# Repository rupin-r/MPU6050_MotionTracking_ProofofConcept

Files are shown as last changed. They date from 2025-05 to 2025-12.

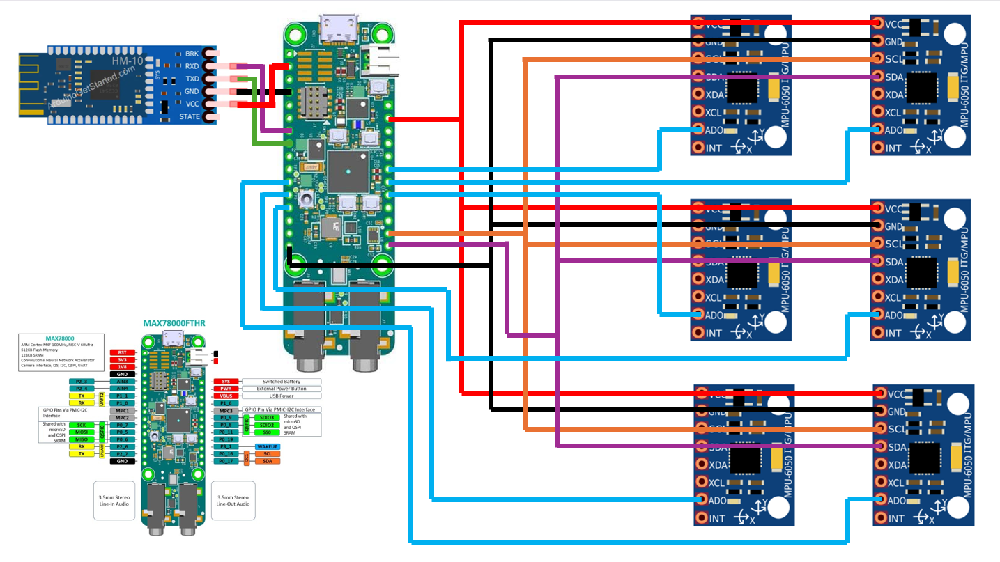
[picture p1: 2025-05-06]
WiringDiagram.png

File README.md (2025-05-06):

# MPU6050_MotionTracking_ProofofConcept
-------------------
About
-------------------

Contributors: Rupin Raj Kumar Pradeep

Project Description: WPI ECE556 Deep Learning On Embedded Devices class project.

Characterize motions into 5 general categories (similar to existing work) of walking, standing, sitting, going upstairs, and going downstairs using 6 MPU6050s placed on the body.

--------------------
Features
--------------------

Includes an Eclipse IDE project generated by the MAXIM_SDK and further edited for input handling and processing. Also includes data for training and testing assuming orientation and position generally matches.

The main code solution is meant to run on a MAX78000FTHR board connected to 6 MPU6050s and a HM-10 or HM-20 BlueTooth module as seen in the wiring diagram presented further down.

--------------------
Required Materials
--------------------

-1 MAX78000FTHR

-6 MPU6050

-1 Breadboard or custom PCB

-30 very long (preferably custom cut) male-to-female wires (for IMU connection to PCB)

-10 short male-to-female wires (for MAX78000FTHR connection to PCB)

-4 short female-to-female wires (typically comes with HM-20 to connect to MAX78000 FTHR

-1 micro-USB to USB A cable with data transfer

-1 Arduino UNO for preliminary data gathering or testing if required

-2 rolls of Velcro strap

-A power source (Arduino kit 9V battery with power supply module is suitable)

-An iPhone with the app BluetoothLE Bluetooth Terminal by Lukas Pistrol
Is it trustworthy? I don't know, but other bluetooth terminals place a character limit at 8 or 16 character transfers

--------------------
Resources and References
--------------------

-Device setup resources and auto-generated deep learning code

https://github.com/analogdevicesinc/MaximAI_Documentation/tree/main/MAX78000_Feather

https://github.com/analogdevicesinc/ai8x-synthesis/blob/develop/README.md

https://analogdevicesinc.github.io/msdk/USERGUIDE/

-Input handling code resources

https://github.com/ElectronicCats/mpu6050/blob/master/src/MPU6050.cpp

https://invensense.tdk.com/wp-content/uploads/2015/02/MPU-6000-Register-Map1.pdf

https://jake-carter.github.io/msdk/Libraries/PeriphDrivers/Documentation/MAX78002/group__i2c.html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

https://jake-carter.github.io/msdk/Libraries/PeriphDrivers/Documentation/MAX32520/group__gpio.html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

https://jake-carter.github.io/msdk/Libraries/PeriphDrivers/Documentation/MAX32650/group__uart.html

https://www.analog.com/media/en/technical-documentation/user-guides/max78000-user-guide.pdf

--------------------
Design
--------------------

***Wiring Diagram***

See file WiringDiagram.png

***MPU Positioning***

See file BodyPlacement.png

***Neural Network Architecture***

See imu.yaml in the Neural Network folder

SUMMARY OF OPS

Hardware: 1,715,382 ops (1,703,817 macc; 11,565 comp; 0 add; 0 mul; 0 bitwise)

    Layer 0 (trans_conv1_ConvTranspose_8): 622,080 ops (622,080 macc; 0 comp; 0 add; 0 mul; 0 bitwise)
    
    Layer 1 (trans_conv2_ConvTranspose_6): 663,552 ops (663,552 macc; 0 comp; 0 add; 0 mul; 0 bitwise)
    
    Layer 2 (conv1_Conv_6): 336,384 ops (331,776 macc; 4,608 comp; 0 add; 0 mul; 0 bitwise)
    
    Layer 3 (conv2_Conv_6): 88,704 ops (82,944 macc; 5,760 comp; 0 add; 0 mul; 0 bitwise)
    
    Layer 4 (conv3_Conv_6): 4,437 ops (3,240 macc; 1,197 comp; 0 add; 0 mul; 0 bitwise)
    
    Layer 5 (fc_Gemm_4): 225 ops (225 macc; 0 comp; 0 add; 0 mul; 0 bitwise)

RESOURCE USAGE
    
    Weight memory: 7,209 bytes out of 442,368 bytes total (1.6%)
    
    Bias memory:   50 bytes out of 2,048 bytes total (2.4%)

AIM

The neural network should be small and extremely, but this was a lot smaller than it could have been considering it takes up < 3% of the processor space.

Since the input is considered small ([30, 6, 6]), the goal was to enlarge the sample first, then go further down to the 5 output classification.

Therefore, the first two layers undergo 2D Convolutional Transpose, but were unable to quickly increase the size due to hardware constraints on kernel size.

The next convolutional layers bring the size back down.

Further work can be done in changing the model to a larger model with more convolutional transposes for better results.

However, irregardless of size, the network was able to have high accuracy with 8-bit quantization (it might also be a little overfit, but that was intentional).

    2025-05-05 01:05:35,825 - ==> Top1: 97.833    Loss: 0.083

    2025-05-05 01:05:35,826 - ==> Confusion:
    
    [[ 373    5    0    0   12]
    
     [   1 3259    1    0   93]
    
     [   0    4 2935    0    1]
     
     [   0    0    1  366    0]
     
     [   1   86    0    0 2324]]

 This was not able to be tested with further real world data because of failed I2C communications and wires breaking. However, it did classify all 0s as sitting which is pretty good.

 CONSIDERATIONS

 The neural network runs in series with data collection. Due to the current I2C characteristics seen on both the Arduino and MAX78000FTHR, each sample takes ~10 ms for a single [1,6,6] capture.
 Therefore, 3 seconds after device and data initialization are needed before the first classification. After the 3 seconds, frames are sampled every second by pushing in 8 frames and popping 8 frames.
 For consistency in collected data from input data to training data, inference time should approach 0. However, if implemented on a separate thread, the inference time would only have to be less than 1 second. 
 In such a case, frame time can be extended for bigger frames and the model can be even bigger.

--------------------
Reproduction
--------------------
 
This guide is specifically for Windows 10/11 using Eclipse SDK

***SETUP DRIVER***

Follow the steps in https://github.com/analogdevicesinc/MaximAI_Documentation/tree/main/MAX78000_Feather for getting started. If the link does not redirect, in the directory on the left hand side, select MAX78000_Evaluation_Kit. Then double click in MAX32625PICO_files. The device driver is there for the adapter firmware.

***SOFTWARE DOWNLOAD***

Go to this link: https://www.analog.com/en/resources/evaluation-hardware-and-software/embedded-development-software/software-download.html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. Then click MaximMicrosSDK_win.exe and download it. You may need to create an account for this. Run the executable and install everything into the default directory. After installing everything, eclipse SDK should be accessible. Before opening eclipse SDK, copy the folder imu_fixed_inputs_no_softmax into C:/MaximSDK/Examples/MAX78000

Run MinGw to setup your environment. Change directory in the terminal of MinGw to the imu_fixed_inputs_no_softmax folder. Run 'make' and ensure the file builds. Once the file is built, you can upload the code to the board using 'make flash.openocd'. If the file doesn't build, you may need to install some additional stuff. This would include cloning the msdk git repository and creating a symbolic link to MaximSDK Tools. Details on these instructions can be found here: https://github.com/analogdevicesinc/msdk/blob/main/README.md

***RUNNING THE PROGRAM***

The program automatically starts after flashing. The program then restarts everytime it is powered on. You can debug the program using MinGw by typing 'openocd -s $MAXIM_PATH/Tools/OpenOCD/scripts -f interface/cmsis-dap.cfg -f target/max78000.cfg -c "program build/max78000.elf verify; init; reset halt"' into one MinGw terminal and 'arm-none-eabi-gdb --se=build/max78000.elf' into another MinGw terminal. The second command starts a gdb debugger. Before you start debugging, type in 'target extended-remote localhost:3333' and press enter. Then run 'monitor reset halt' and you can debug the program. More information can be found here: https://analogdevicesinc.github.io/msdk/USERGUIDE/#command-line-development

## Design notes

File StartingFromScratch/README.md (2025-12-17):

# Programming a Model from Scratch
-------------------
Instructions
-------------------

Most instructions for setting up and running a model can be found by altering instructions for mnist in the tutorial found here: https://github.com/analogdevicesinc/ai8x-synthesis/blob/develop/README.md and here: https://github.com/analogdevicesinc/ai8x-training?tab=readme-ov-file

The instructions found here are a simplification specific to the data presented here and Windows 10/11 with Windows Subsystem for Linux.

***Install Ubuntu 22.04.5***

Open a command prompt as administrator and run:

    C:\> wsl --install

Then restart your computer (not just your terminal)

Open the Microsoft store and install Ubuntu 22.04.5

You can now open a WSL terminal by searching Ubuntu in the start bar

Open a WSL terminal and run:

    sudo apt upgrade

    sudo apt update

Then run the following command to install dependencies:

    sudo apt-get install -y make build-essential libssl-dev zlib1g-dev libbz2-dev libreadline-dev libsqlite3-dev wget curl llvm libncurses5-dev libncursesw5-dev xz-utils tk-dev libffi-dev liblzma-dev libsndfile-dev portaudio19-dev libsox-dev

After installing dependencies, install python3 with:

    curl -L https://github.com/pyenv/pyenv-installer/raw/master/bin/pyenv-installer | bash

The terminal will then prompt you to add lines to one or more of ~/.bash_profile, ~/.bashrc, ~/.zshrc, ~/.profile, or ~/.zprofile

You can open one of these files using nano to edit them. For instance:

    nano ~/.profile

Copy the lines given to you at the end of the files prompted by the terminal. Using nano, use CTRL + X to exit and save to a file.

Close the terminal and open a new WSL terminal

***Install ai8x-trainer and ai8x-synthesizer***

Install python using:

    pyenv install 3.11.8

Establish git profile using:

    git config --global user.email "email@example.com"

    git config --global user.name "username"

Create a directory to store your files in with mkdir:

    mkdir example

    cd example

Then clone the repositories into this directory:

    git clone --recursive https://github.com/analogdevicesinc/ai8x-training.git

    git clone --recursive https://github.com/analogdevicesinc/ai8x-synthesis.gi

Run the following lines to set up a virtual environment to use in the training folder:

    cd ai8x-training

    pyenv local 3.11.8

    python -m venv .venv --prompt ai8x-training

    echo "*" > .venv/.gitignore

    source .venv/bin/activate

You can exit the virtual environment using:

    deactivate

You can restart the virtual environment for any work you need to do in training just with:

    source .venv/bin/activate

Before deactivating the training virtual environment (or restart it if you have), install more dependencies:

    pip3 install -U pip wheel setuptools

    pip3 install -r requirements.txt --extra-index-url https://download.pytorch.org/whl/cu121

Run the following lines to set up a virtual environment to use in the synthesis folder:

    cd ../ai8x-synthesis

    pyenv local 3.11.8

    python -m venv .venv --prompt ai8x-synthesis

    echo "*" > .venv/.gitignore

    source .venv/bin/activate

You can exit the virtual environment using:

    deactivate

You can restart the virtual environment for any work you need to do in training just with:

    source .venv/bin/activate

Again, before deactivating, install more dependencies:

    pip3 install -U pip setuptools

    pip3 install -r requirements.txt

***Data Loader***

To start training the model, the data must be loaded into a created/selected model

Specifically, data must be accessible through the dataset class as it allows for indexed access of data

You can follow the template given by training/imu.py which loads data from a json file

The class IMU_AI holds the dataset and allows for indexing of elements of the dataset. It also contains a loader which gives access to both the train and test datasets.

These must then be defined in a dataset construct at the end as shown in the file

Then you need to select/create a model. The github for training and synthesis comes with premade models, but you can choose to make your own following the same format. I chose to use a premade model: ai85net.py

Lastly, you put all these parameters together into the training file to actually train the model. There are two main files to look at: train_kinetics.sh and evaluate_kinetics.sh. These files were edited from their original implementation as an example to use with the IMU dataset of this project.

You can edit any parameters for training or evaluating the model and more details can be found on their website: https://github.com/analogdevicesinc/ai8x-training?tab=readme-ov-file

***Synthesizing***

Synthesizing turns the created model into an embedded C program for the TPU on the MAX78000 to run

First you need a model formatted to yaml as seen in synthesis/imu.yaml

This was taken from the example ai85net as well

You then need to copy over a checkpoint tar file from training to synthesis that you would like to load onto the TPU

You also need a sample input data in the form of .npy. You can choose to either use a random input generation in python or save an input slice from the evaluation dataset. The parameter --save-sample _ saves an input slice as a .npy file. synthesis/sample_imu_ai.py is an example of a slice of input 5 as seen in training/evaluate_kinetics.sh at the end.

After gathering these three inputs, you can run ai8xize.py

Again, more information can be found on their website: https://github.com/analogdevicesinc/ai8x-training?tab=readme-ov-file, but closer to the bottom for synthesis.

***Coding***

Synthesis will generate basically an entire eclipse project

You simply need to load the project into eclipse and you can start coding

main.c is the place to start coding and you can add additional files and methods as needed

The code I have implements I2C multiplexing among 6 MPU6050 and an additional UART protocol for Bluetooth readout

To start the TPU, first run 

    cnn_enable(MXC_S_GCR_PCLKDIV_CNNCLKSEL_PCLK, MXC_S_GCR_PCLKDIV_CNNCLKDIV_DIV1); 
    
which runs the TPU with a 50 MHz clock

Then run 

    cnn_init(); // Bring state machine into consistent state

    cnn_load_weights(); // Load kernels

    cnn_load_bias();

    cnn_configure(); // Configure state machine

Data can be placed into an array memory mapped to the TPU using memcpy. I use a dedicated method to transfer array data into the correct location in memory for the TPU.

Lastly, run 

    cnn_start(); // Start CNN processing

	while (cnn_time == 0)
	
        MXC_LP_EnterSleepMode(); // Wait for CNN
		
    cnn_unload((uint32_t*) ml_data);

To run the TPU with the loaded data and wait for outputs. In this case, outputs are placed into a uint32 pointer and can be read out in order.

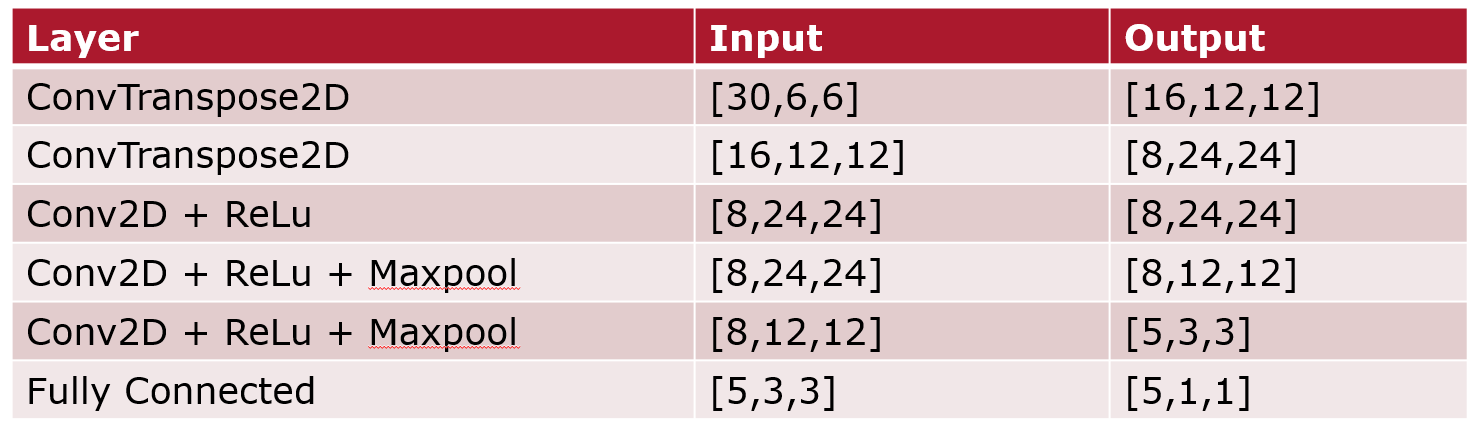
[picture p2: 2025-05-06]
NeuralNetworkStructure.png

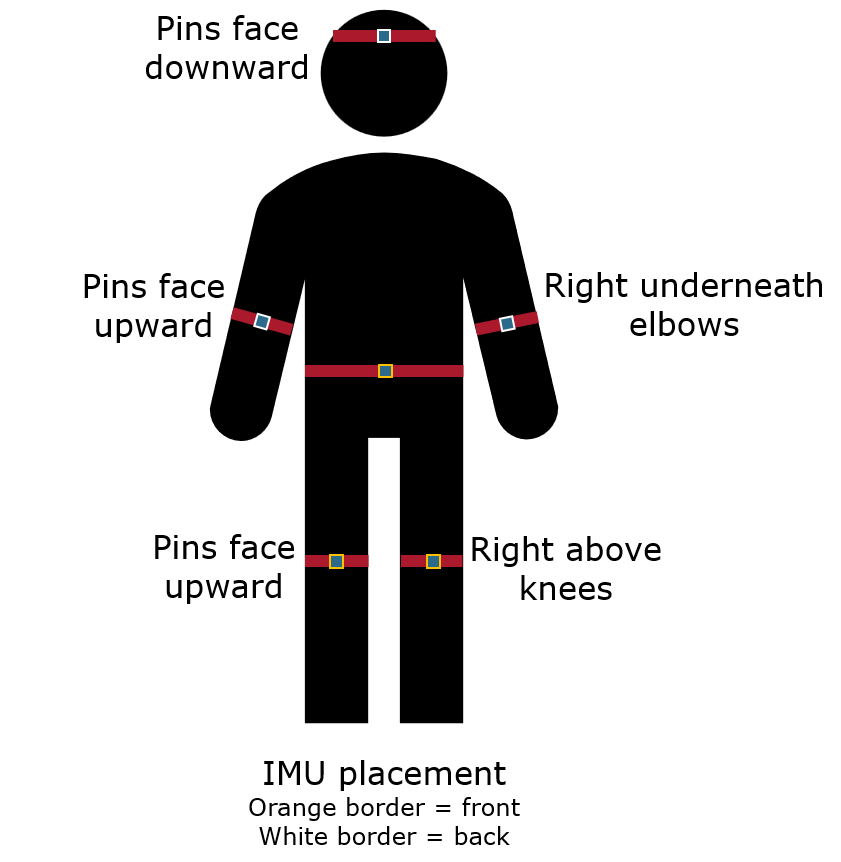
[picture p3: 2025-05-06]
BodyPlacement.png

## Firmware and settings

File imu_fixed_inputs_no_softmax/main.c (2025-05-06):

/******************************************************************************
 *
 * Copyright (C) 2022-2023 Maxim Integrated Products, Inc. (now owned by
 * Analog Devices, Inc.),
 * Copyright (C) 2023-2024 Analog Devices, Inc.
 *
 * Licensed under the Apache License, Version 2.0 (the "License");
 * you may not use this file except in compliance with the License.
 * You may obtain a copy of the License at
 *
 *     http://www.apache.org/licenses/LICENSE-2.0
 *
 * Unless required by applicable law or agreed to in writing, software
 * distributed under the License is distributed on an "AS IS" BASIS,
 * WITHOUT WARRANTIES OR CONDITIONS OF ANY KIND, either express or implied.
 * See the License for the specific language governing permissions and
 * limitations under the License.
 *
 ******************************************************************************/

/**
 * @file        main.c
 * @brief       I2C Loopback Example
 * @details     This example uses the I2C Master to read/write from/to the I2C Slave. For
 *              this example you must connect P0.10 to P0.16 (SCL) and P0.11 to P0.17 (SCL). The Master
 *              will use P0.10 and P0.11. The Slave will use P0.16 and P0.17. You must also
 *              connect the pull-up jumpers (JP21 and JP22) to the proper I/O voltage.
 */

/***** Includes *****/
#include <stdio.h>
#include <stdint.h>
#include <string.h>
#include <stdlib.h>
#include "board.h"
#include "mxc_device.h"
#include "mxc_delay.h"
#include "nvic_table.h"
#include "i2c.h"
#include "gpio.h"
#include "uart.h"
#include "mxc.h"
#include "cnn.h"
#include "sampledata.h"
#include "sampleoutput.h"

/***** Definitions *****/
#define PMIC_I2C MXC_I2C1

#define I2C_FREQ 115200
#define PMIC_SLAVE_ADDR (0x69)
#define INIT_READ_LEN 1
#define INIT_WRITE_LEN 2
#define READ_LEN 14

#define CLKSEL 1
#define GYRO_RANGE 0
#define ACC_RANGE 0
#define SLEEP 1

#define RL_PORT MXC_GPIO0
#define LL_PORT MXC_GPIO0
#define W_PORT MXC_GPIO0
#define RA_PORT MXC_GPIO0
#define LA_PORT MXC_GPIO0
#define H_PORT MXC_GPIO0
#define RL_PIN MXC_GPIO_PIN_5
#define LL_PIN MXC_GPIO_PIN_6
#define W_PIN MXC_GPIO_PIN_7
#define RA_PIN MXC_GPIO_PIN_8
#define LA_PIN MXC_GPIO_PIN_9
#define H_PIN MXC_GPIO_PIN_11

#define HM20_UART MXC_UART2
#define HM20_BAUDRATE 57600
#define BUFF_SIZE 64

/***** Globals *****/
static uint8_t tx_buf[INIT_WRITE_LEN];
static uint8_t rx_buf[INIT_READ_LEN];
static uint8_t tx_data[BUFF_SIZE];

static uint8_t ack_RL[BUFF_SIZE];
static uint8_t ack_LL[BUFF_SIZE];
static uint8_t ack_W[BUFF_SIZE];
static uint8_t ack_RA[BUFF_SIZE];
static uint8_t ack_LA[BUFF_SIZE];
static uint8_t ack_H[BUFF_SIZE];

static uint32_t cnn_input0[36];
static uint32_t cnn_input4[36];
static uint32_t cnn_input8[36];
static uint32_t cnn_input12[36];
static uint32_t cnn_input16[36];
static uint32_t cnn_input20[36];
static uint32_t cnn_input24[36];
static uint32_t cnn_input28[36];

static uint8_t result0[BUFF_SIZE];
static uint8_t result1[BUFF_SIZE];
static uint8_t result2[BUFF_SIZE];
static uint8_t result3[BUFF_SIZE];
static uint8_t result4[BUFF_SIZE];

static int32_t ml_data[CNN_NUM_OUTPUTS];
static char temp_display[BUFF_SIZE];

volatile uint32_t cnn_time; // Stopwatch

/***** Functions *****/

void fail(void) {
	printf("\n*** FAIL ***\n\n");
	while (1)
		;
}

void GPIO_init(void) {
	mxc_gpio_cfg_t gpio_cfg1;
	gpio_cfg1.port = RL_PORT;
	gpio_cfg1.mask = RL_PIN;
	gpio_cfg1.pad = MXC_GPIO_PAD_NONE;
	gpio_cfg1.func = MXC_GPIO_FUNC_OUT;
	gpio_cfg1.vssel = MXC_GPIO_VSSEL_VDDIOH;
	gpio_cfg1.drvstr = MXC_GPIO_DRVSTR_3;

	MXC_GPIO_Config(&gpio_cfg1);

	mxc_gpio_cfg_t gpio_cfg2;
	gpio_cfg2.port = LL_PORT;
	gpio_cfg2.mask = LL_PIN;
	gpio_cfg2.pad = MXC_GPIO_PAD_NONE;
	gpio_cfg2.func = MXC_GPIO_FUNC_OUT;
	gpio_cfg2.vssel = MXC_GPIO_VSSEL_VDDIOH;
	gpio_cfg2.drvstr = MXC_GPIO_DRVSTR_3;

	MXC_GPIO_Config(&gpio_cfg2);

	mxc_gpio_cfg_t gpio_cfg3;
	gpio_cfg3.port = W_PORT;
	gpio_cfg3.mask = W_PIN;
	gpio_cfg3.pad = MXC_GPIO_PAD_NONE;
	gpio_cfg3.func = MXC_GPIO_FUNC_OUT;
	gpio_cfg3.vssel = MXC_GPIO_VSSEL_VDDIOH;
	gpio_cfg3.drvstr = MXC_GPIO_DRVSTR_3;

	MXC_GPIO_Config(&gpio_cfg3);

	mxc_gpio_cfg_t gpio_cfg4;
	gpio_cfg4.port = RA_PORT;
	gpio_cfg4.mask = RA_PIN;
	gpio_cfg4.pad = MXC_GPIO_PAD_NONE;
	gpio_cfg4.func = MXC_GPIO_FUNC_OUT;
	gpio_cfg4.vssel = MXC_GPIO_VSSEL_VDDIOH;
	gpio_cfg4.drvstr = MXC_GPIO_DRVSTR_3;

	MXC_GPIO_Config(&gpio_cfg4);

	mxc_gpio_cfg_t gpio_cfg5;
	gpio_cfg5.port = LA_PORT;
	gpio_cfg5.mask = LA_PIN;
	gpio_cfg5.pad = MXC_GPIO_PAD_NONE;
	gpio_cfg5.func = MXC_GPIO_FUNC_OUT;
	gpio_cfg5.vssel = MXC_GPIO_VSSEL_VDDIOH;
	gpio_cfg5.drvstr = MXC_GPIO_DRVSTR_3;

	MXC_GPIO_Config(&gpio_cfg5);

	mxc_gpio_cfg_t gpio_cfg6;
	gpio_cfg6.port = H_PORT;
	gpio_cfg6.mask = H_PIN;
	gpio_cfg6.pad = MXC_GPIO_PAD_NONE;
	gpio_cfg6.func = MXC_GPIO_FUNC_OUT;
	gpio_cfg6.vssel = MXC_GPIO_VSSEL_VDDIOH;
	gpio_cfg6.drvstr = MXC_GPIO_DRVSTR_3;

	MXC_GPIO_Config(&gpio_cfg6);
}

void I2C_init(void) {
	int error = 0;

	//Setup the I2CM
	error = MXC_I2C_Init(PMIC_I2C, 1, 0x69);

	if (error != E_NO_ERROR) {
		printf("-->Failed master\n");
		while (1) {
		}
	} else {
		printf("\n-->I2C Initialization Complete");
	}

	MXC_I2C_SetFrequency(PMIC_I2C, I2C_FREQ);

	return;
}

void clearCNNInput(void) {
	memset(cnn_input0, 0, sizeof(cnn_input0));
	memset(cnn_input4, 0, sizeof(cnn_input4));
	memset(cnn_input8, 0, sizeof(cnn_input8));
	memset(cnn_input12, 0, sizeof(cnn_input12));
	memset(cnn_input16, 0, sizeof(cnn_input16));
	memset(cnn_input20, 0, sizeof(cnn_input20));
	memset(cnn_input24, 0, sizeof(cnn_input24));
	memset(cnn_input28, 0, sizeof(cnn_input28));
}

void load_input(void) {
	// This function loads the sample data input -- replace with actual data

	memcpy32((uint32_t*) 0x50400000, cnn_input0, 36);
	memcpy32((uint32_t*) 0x50408000, cnn_input4, 36);
	memcpy32((uint32_t*) 0x50410000, cnn_input8, 36);
	memcpy32((uint32_t*) 0x50418000, cnn_input12, 36);
	memcpy32((uint32_t*) 0x50800000, cnn_input16, 36);
	memcpy32((uint32_t*) 0x50808000, cnn_input20, 36);
	memcpy32((uint32_t*) 0x50810000, cnn_input24, 36);
	memcpy32((uint32_t*) 0x50818000, cnn_input28, 36);
}

bool MPU_init(mxc_i2c_req_t reqMaster) {
	int error;

	MXC_Delay(MXC_DELAY_MSEC(1));

	reqMaster.i2c = PMIC_I2C;
	reqMaster.addr = PMIC_SLAVE_ADDR;
	reqMaster.tx_buf = tx_buf;
	reqMaster.tx_len = INIT_READ_LEN;
	reqMaster.rx_buf = rx_buf;
	reqMaster.rx_len = INIT_READ_LEN;
	reqMaster.restart = 0;

	tx_buf[0] = 0x6B;

	MXC_Delay(MXC_DELAY_MSEC(1));

	if ((error = MXC_I2C_MasterTransaction(&reqMaster)) != 0) {
		printf("error: %d", error);
		return true;
	}

	MXC_Delay(MXC_DELAY_MSEC(1));

	tx_buf[1] = (rx_buf[0] & 0xF8) | CLKSEL;

	reqMaster.tx_buf = tx_buf;
	reqMaster.tx_len = INIT_WRITE_LEN;
	reqMaster.rx_buf = NULL;
	reqMaster.rx_len = 0;

	tx_buf[1] = (rx_buf[0] & 0xF8) | CLKSEL;

	MXC_Delay(MXC_DELAY_MSEC(1));

	if ((error = MXC_I2C_MasterTransaction(&reqMaster)) != 0) {
		return true;
	}

	MXC_Delay(MXC_DELAY_MSEC(1));

	tx_buf[0] = 0x1B;
	rx_buf[0] = 0;

	reqMaster.tx_buf = tx_buf;
	reqMaster.tx_len = INIT_READ_LEN;
	reqMaster.rx_buf = rx_buf;
	reqMaster.rx_len = INIT_READ_LEN;

	MXC_Delay(MXC_DELAY_MSEC(1));

	if ((error = MXC_I2C_MasterTransaction(&reqMaster)) != 0) {
		return true;
	}

	MXC_Delay(MXC_DELAY_MSEC(1));

	tx_buf[1] = (rx_buf[0] & 0xE7);

	reqMaster.tx_buf = tx_buf;
	reqMaster.tx_len = INIT_WRITE_LEN;
	reqMaster.rx_buf = NULL;
	reqMaster.rx_len = 0;

	MXC_Delay(MXC_DELAY_MSEC(1));

	if ((error = MXC_I2C_MasterTransaction(&reqMaster)) != 0) {
		return true;
	}

	MXC_Delay(MXC_DELAY_MSEC(1));

	tx_buf[0] = 0x1C;
	rx_buf[0] = 0;

	reqMaster.tx_buf = tx_buf;
	reqMaster.tx_len = INIT_READ_LEN;
	reqMaster.rx_buf = rx_buf;
	reqMaster.rx_len = INIT_READ_LEN;

	MXC_Delay(MXC_DELAY_MSEC(1));

	if ((error = MXC_I2C_MasterTransaction(&reqMaster)) != 0) {
		return true;
	}

	MXC_Delay(MXC_DELAY_MSEC(1));

	tx_buf[1] = (rx_buf[0] & 0xE7);

	reqMaster.tx_buf = tx_buf;
	reqMaster.tx_len = INIT_WRITE_LEN;
	reqMaster.rx_buf = NULL;
	reqMaster.rx_len = 0;

	MXC_Delay(MXC_DELAY_MSEC(1));

	if ((error = MXC_I2C_MasterTransaction(&reqMaster)) != 0) {
		return true;
	}

	MXC_Delay(MXC_DELAY_MSEC(1));

	tx_buf[0] = 0x6B;
	rx_buf[0] = 0;

	reqMaster.tx_buf = tx_buf;
	reqMaster.tx_len = INIT_READ_LEN;
	reqMaster.rx_buf = rx_buf;
	reqMaster.rx_len = INIT_READ_LEN;

	MXC_Delay(MXC_DELAY_MSEC(1));

	if ((error = MXC_I2C_MasterTransaction(&reqMaster)) != 0) {
		return true;
	}

	MXC_Delay(MXC_DELAY_MSEC(1));

	tx_buf[1] = (rx_buf[0] & 0xBF);

	reqMaster.tx_buf = tx_buf;
	reqMaster.tx_len = INIT_WRITE_LEN;
	reqMaster.rx_buf = NULL;
	reqMaster.rx_len = 0;

	MXC_Delay(MXC_DELAY_MSEC(1));

	if ((error = MXC_I2C_MasterTransaction(&reqMaster)) != 0) {
		return true;
	}

	MXC_Delay(MXC_DELAY_MSEC(1));

	return false;
}

int main(void) {

	clearCNNInput();

	MXC_ICC_Enable(MXC_ICC0); // Enable cache

	// Switch to 100 MHz clock
	MXC_SYS_Clock_Select(MXC_SYS_CLOCK_IPO);
	SystemCoreClockUpdate();

	printf("Waiting...\n");

	// DO NOT DELETE THIS LINE:
	MXC_Delay(SEC(2)); // Let debugger interrupt if needed

	// Enable peripheral, enable CNN interrupt, turn on CNN clock
	// CNN clock: APB (50 MHz) div 1
	cnn_enable(MXC_S_GCR_PCLKDIV_CNNCLKSEL_PCLK,
	MXC_S_GCR_PCLKDIV_CNNCLKDIV_DIV1);

	printf("\n*** CNN Inference Test imu_fixed_inputs_no_softmax ***\n");

	cnn_init(); // Bring state machine into consistent state
	cnn_load_weights(); // Load kernels
	cnn_load_bias();
	cnn_configure(); // Configure state machine

	const char *msg = "Hello from MAX78000\r\n";
	const char *done1 = "Completed initializing RL\r\n";
	const char *done2 = "Completed initializing LL\r\n";
	const char *done3 = "Completed initializing W\r\n";
	const char *done4 = "Completed initializing RA\r\n";
	const char *done5 = "Completed initializing LA\r\n";
	const char *done6 = "Completed initializing H\r\n";

	const char *downstairs = "You are probably going downstairs\r\n";
	const char *sitting = "You are probably sitting\r\n";
	const char *standing = "You are probably standing\r\n";
	const char *upstairs = "You are probably going upstairs\r\n";
	const char *walking = "You are probably walking\r\n";

	// Initialize UART1
	int err = MXC_UART_Init(HM20_UART, HM20_BAUDRATE, MXC_UART_APB_CLK);

	if (err != E_NO_ERROR) {
		printf("UART init failed: %d\n", err);
		while (1)
			;
	}

	mxc_uart_req_t write_req;
	write_req.uart = HM20_UART;
	write_req.txData = tx_data;
	write_req.txLen = BUFF_SIZE;
	write_req.rxLen = 0;
	write_req.callback = NULL;

	for (int i = 0; i < strlen(msg); i++) {
		tx_data[i] = msg[i];
	}
	for (int j = strlen(msg); j < BUFF_SIZE; j++) {
		tx_data[j] = '\0';
	}

	for (int i = 0; i < strlen(downstairs); i++) {
		result0[i] = downstairs[i];
	}
	for (int j = strlen(downstairs); j < BUFF_SIZE; j++) {
		result0[j] = '\0';
	}

	for (int i = 0; i < strlen(sitting); i++) {
		result1[i] = sitting[i];
	}
	for (int j = strlen(sitting); j < BUFF_SIZE; j++) {
		result1[j] = '\0';
	}

	for (int i = 0; i < strlen(standing); i++) {
		result2[i] = standing[i];
	}
	for (int j = strlen(standing); j < BUFF_SIZE; j++) {
		result2[j] = '\0';
	}

	for (int i = 0; i < strlen(upstairs); i++) {
		result3[i] = upstairs[i];
	}
	for (int j = strlen(upstairs); j < BUFF_SIZE; j++) {
		result3[j] = '\0';
	}

	for (int i = 0; i < strlen(walking); i++) {
		result4[i] = walking[i];
	}
	for (int j = strlen(walking); j < BUFF_SIZE; j++) {
		result4[j] = '\0';
	}

	for (int i = 0; i < strlen(done1); i++) {
		ack_RL[i] = done1[i];
	}
	for (int j = strlen(msg); j < BUFF_SIZE; j++) {
		ack_RL[j] = '\0';
	}

	for (int i = 0; i < strlen(done2); i++) {
		ack_LL[i] = done2[i];
	}
	for (int j = strlen(msg); j < BUFF_SIZE; j++) {
		ack_LL[j] = '\0';
	}

	for (int i = 0; i < strlen(done3); i++) {
		ack_W[i] = done3[i];
	}
	for (int j = strlen(msg); j < BUFF_SIZE; j++) {
		ack_W[j] = '\0';
	}

	for (int i = 0; i < strlen(done4); i++) {
		ack_RA[i] = done4[i];
	}
	for (int j = strlen(msg); j < BUFF_SIZE; j++) {
		ack_RA[j] = '\0';
	}

	for (int i = 0; i < strlen(done5); i++) {
		ack_LA[i] = done5[i];
	}
	for (int j = strlen(msg); j < BUFF_SIZE; j++) {
		ack_LA[j] = '\0';
	}

	for (int i = 0; i < strlen(done6); i++) {
		ack_H[i] = done6[i];
	}
	for (int j = strlen(msg); j < BUFF_SIZE; j++) {
		ack_H[j] = '\0';
	}

	// Optional: Wait for HM-10 to power up
	MXC_Delay(MXC_DELAY_MSEC(1000));

	int error;

	error = MXC_UART_Transaction(&write_req);

	if (error != E_NO_ERROR) {
		printf("-->Error starting sync write: %d\n", error);
	}

	MXC_Delay(MXC_DELAY_MSEC(500)); //Wait for PMIC to power-up

	GPIO_init();

	MXC_GPIO_OutClr(RL_PORT, RL_PIN);
	MXC_GPIO_OutClr(LL_PORT, LL_PIN);
	MXC_GPIO_OutClr(W_PORT, W_PIN);
	MXC_GPIO_OutClr(RA_PORT, RA_PIN);
	MXC_GPIO_OutClr(LA_PORT, LA_PIN);
	MXC_GPIO_OutClr(H_PORT, H_PIN);

	MXC_GPIO_OutSet(W_PORT, W_PIN);

	I2C_init();

	MXC_I2C_SetTimeout(PMIC_I2C, 100000);

	mxc_i2c_req_t reqMaster;
	reqMaster.i2c = PMIC_I2C;
	reqMaster.addr = PMIC_SLAVE_ADDR;
	reqMaster.tx_buf = tx_buf;
	reqMaster.tx_len = INIT_READ_LEN;
	reqMaster.rx_buf = rx_buf;
	reqMaster.rx_len = INIT_READ_LEN;
	reqMaster.restart = 1;

	//tx_buf[0] = 0x75;

	//if ((error = MXC_I2C_MasterTransaction(&reqMaster)) != 0) {
	//    printf("Error writing: %d\n", error);
	//    while (1) {}
	//}

	MXC_Delay(MXC_DELAY_MSEC(1));
	MXC_GPIO_OutSet(RL_PORT, RL_PIN);
	MXC_Delay(MXC_DELAY_MSEC(100));

	bool skip_RL = MPU_init(reqMaster);
	//while (skip_RL) {
	//	skip_RL = MPU_init(reqMaster);
	//}

	MXC_Delay(MXC_DELAY_MSEC(100));
	MXC_GPIO_OutClr(RL_PORT, RL_PIN);

	write_req.txData = ack_RL;
	error = MXC_UART_Transaction(&write_req);

	if (error != E_NO_ERROR) {
		printf("-->Error starting sync write: %d\n", error);
	}
	MXC_Delay(MXC_DELAY_MSEC(1));

	MXC_GPIO_OutSet(LL_PORT, LL_PIN);
	MXC_Delay(MXC_DELAY_MSEC(100));

	bool skip_LL = MPU_init(reqMaster);
	//while (skip_LL) {
	//	skip_LL = MPU_init(reqMaster);
	//}

	MXC_Delay(MXC_DELAY_MSEC(100));
	MXC_GPIO_OutClr(LL_PORT, LL_PIN);

	write_req.txData = ack_LL;
	error = MXC_UART_Transaction(&write_req);

	if (error != E_NO_ERROR) {
		printf("-->Error starting sync write: %d\n", error);
	}
	MXC_Delay(MXC_DELAY_MSEC(1));

	MXC_GPIO_OutSet(W_PORT, W_PIN);
	MXC_Delay(MXC_DELAY_MSEC(100));

	bool skip_W = MPU_init(reqMaster);
	//while (skip_W) {
	//	skip_W = MPU_init(reqMaster);
	//}

	MXC_Delay(MXC_DELAY_MSEC(100));
	MXC_GPIO_OutClr(W_PORT, W_PIN);

	write_req.txData = ack_W;
	error = MXC_UART_Transaction(&write_req);

	if (error != E_NO_ERROR) {
		printf("-->Error starting sync write: %d\n", error);
	}
	MXC_Delay(MXC_DELAY_MSEC(1));

	MXC_GPIO_OutSet(RA_PORT, RA_PIN);
	MXC_Delay(MXC_DELAY_MSEC(100));

	bool skip_RA = MPU_init(reqMaster);
	//while (skip_RA) {
	//	skip_RA = MPU_init(reqMaster);
	//}

	MXC_Delay(MXC_DELAY_MSEC(100));
	MXC_GPIO_OutClr(RA_PORT, RA_PIN);

	write_req.txData = ack_RA;
	error = MXC_UART_Transaction(&write_req);

	if (error != E_NO_ERROR) {
		printf("-->Error starting sync write: %d\n", error);
	}
	MXC_Delay(MXC_DELAY_MSEC(1));

	MXC_GPIO_OutSet(LA_PORT, LA_PIN);
	MXC_Delay(MXC_DELAY_MSEC(100));

	bool skip_LA = MPU_init(reqMaster);
	//while (skip_LA) {
	//	skip_LA = MPU_init(reqMaster);
	//}

	MXC_Delay(MXC_DELAY_MSEC(100));
	MXC_GPIO_OutClr(LA_PORT, LA_PIN);

	write_req.txData = ack_LA;
	error = MXC_UART_Transaction(&write_req);

	if (error != E_NO_ERROR) {
		printf("-->Error starting sync write: %d\n", error);
	}
	MXC_Delay(MXC_DELAY_MSEC(1));

	MXC_GPIO_OutSet(H_PORT, H_PIN);
	MXC_Delay(MXC_DELAY_MSEC(100));

	bool skip_H = MPU_init(reqMaster);
	//while (skip_H) {
	//	skip_H = MPU_init(reqMaster);
	//}

	MXC_Delay(MXC_DELAY_MSEC(100));
	MXC_GPIO_OutClr(H_PORT, H_PIN);
	MXC_Delay(MXC_DELAY_MSEC(1));

	write_req.txData = ack_H;
	error = MXC_UART_Transaction(&write_req);

	if (error != E_NO_ERROR) {
		printf("-->Error starting sync write: %d\n", error);
	}

	MXC_Delay(MXC_DELAY_MSEC(1));

	write_req.txData = tx_data;

	reqMaster.tx_buf = tx_buf;
	reqMaster.tx_len = INIT_READ_LEN;
	reqMaster.rx_buf = rx_buf;
	reqMaster.rx_len = INIT_READ_LEN;

	tx_buf[0] = 0x3B;

	int prev[36] = { 0, 0, 0, 0, 0, 0, 0, 0, 0, 0, 0, 0, 0, 0, 0, 0, 0, 0, 0, 0,
			0, 0, 0, 0, 0, 0, 0, 0, 0, 0, 0, 0, 0, 0, 0, 0 };
	int frame[6][6] = { { 0, 0, 0, 0, 0, 0 }, { 0, 0, 0, 0, 0, 0 }, { 0, 0, 0,
			0, 0, 0 }, { 0, 0, 0, 0, 0, 0 }, { 0, 0, 0, 0, 0, 0 }, { 0, 0, 0, 0,
			0, 0 } };

	int frame_count = 0;

	while (1) {
		int ax = 0;
		int ay = 0;
		int az = 0;
		int gx = 0;
		int gy = 0;
		int gz = 0;

		rx_buf[0] = 0;
		//if (!skip_RL) {
		MXC_GPIO_OutSet(RL_PORT, RL_PIN);
		tx_buf[0] = 0x3B;
		MXC_Delay(MXC_DELAY_MSEC(1));
		if ((error = MXC_I2C_MasterTransaction(&reqMaster)) != 0) {
			error = (error * -1) + 48;
			tx_data[36] = (char) (error);
			rx_buf[0] = 0;
		}
		ax = rx_buf[0];
		tx_buf[0] = 0x3C;
		MXC_Delay(MXC_DELAY_MSEC(1));
		if ((error = MXC_I2C_MasterTransaction(&reqMaster)) != 0) {
			error = (error * -1) + 48;
			tx_data[36] = (char) (error);
			rx_buf[0] = 0;
		}
		ax = (ax << 8) | rx_buf[0];
		tx_buf[0] = 0x3D;
		MXC_Delay(MXC_DELAY_MSEC(1));
		if ((error = MXC_I2C_MasterTransaction(&reqMaster)) != 0) {
			error = (error * -1) + 48;
			tx_data[36] = (char) (error);
			rx_buf[0] = 0;
		}
		ay = rx_buf[0];
		tx_buf[0] = 0x3E;
		MXC_Delay(MXC_DELAY_MSEC(1));
		if ((error = MXC_I2C_MasterTransaction(&reqMaster)) != 0) {
			error = (error * -1) + 48;
			tx_data[36] = (char) (error);
			rx_buf[0] = 0;
		}
		ay = (ay << 8) | rx_buf[0];
		tx_buf[0] = 0x3F;
		MXC_Delay(MXC_DELAY_MSEC(1));
		if ((error = MXC_I2C_MasterTransaction(&reqMaster)) != 0) {
			error = (error * -1) + 48;
			tx_data[36] = (char) (error);
			rx_buf[0] = 0;
		}
		az = rx_buf[0];
		tx_buf[0] = 0x40;
		MXC_Delay(MXC_DELAY_MSEC(1));
		if ((error = MXC_I2C_MasterTransaction(&reqMaster)) != 0) {
			error = (error * -1) + 48;
			tx_data[36] = (char) (error);
			rx_buf[0] = 0;
		}
		az = (az << 8) | rx_buf[0];

		tx_buf[0] = 0x43;
		MXC_Delay(MXC_DELAY_MSEC(1));
		if ((error = MXC_I2C_MasterTransaction(&reqMaster)) != 0) {
			error = (error * -1) + 48;
			tx_data[36] = (char) (error);
			rx_buf[0] = 0;
		}
		gx = rx_buf[0];
		tx_buf[0] = 0x44;
		MXC_Delay(MXC_DELAY_MSEC(1));
		if ((error = MXC_I2C_MasterTransaction(&reqMaster)) != 0) {
			error = (error * -1) + 48;
			tx_data[36] = (char) (error);
			rx_buf[0] = 0;
		}
		gx = (gx << 8) | rx_buf[0];
		tx_buf[0] = 0x45;
		MXC_Delay(MXC_DELAY_MSEC(1));
		if ((error = MXC_I2C_MasterTransaction(&reqMaster)) != 0) {
			error = (error * -1) + 48;
			tx_data[36] = (char) (error);
			rx_buf[0] = 0;
		}
		gy = rx_buf[0];
		tx_buf[0] = 0x46;
		MXC_Delay(MXC_DELAY_MSEC(1));
		if ((error = MXC_I2C_MasterTransaction(&reqMaster)) != 0) {
			error = (error * -1) + 48;
			tx_data[36] = (char) (error);
			rx_buf[0] = 0;
		}
		gy = (gy << 8) | rx_buf[0];
		tx_buf[0] = 0x47;
		MXC_Delay(MXC_DELAY_MSEC(1));
		if ((error = MXC_I2C_MasterTransaction(&reqMaster)) != 0) {
			error = (error * -1) + 48;
			tx_data[36] = (char) (error);
			rx_buf[0] = 0;
		}
		gz = rx_buf[0];
		tx_buf[0] = 0x48;
		MXC_Delay(MXC_DELAY_MSEC(1));
		if ((error = MXC_I2C_MasterTransaction(&reqMaster)) != 0) {
			error = (error * -1) + 48;
			tx_data[36] = (char) (error);
			rx_buf[0] = 0;
		}
		gz = (gz << 8) | rx_buf[0];

		MXC_Delay(MXC_DELAY_MSEC(1));
		MXC_GPIO_OutClr(RL_PORT, RL_PIN);
		MXC_Delay(MXC_DELAY_MSEC(1));
		//} else {
		//	tx_data[36] = 52;
		//}
		//Do the rx_buf parsing here
		frame[0][0] = (abs(prev[0] - ax) / 128) - 128;
		prev[0] = ax;
		frame[0][1] = (abs(prev[1] - ay) / 128) - 128;
		prev[1] = ay;
		frame[0][2] = (abs(prev[2] - az) / 128) - 128;
		prev[2] = az;
		frame[0][3] = (abs(prev[3] - gx) / 128) - 128;
		prev[3] = gx;
		frame[0][4] = (abs(prev[4] - gy) / 128) - 128;
		prev[4] = gy;
		frame[0][5] = (abs(prev[5] - gz) / 128) - 128;
		prev[5] = gz;

		rx_buf[0] = 0;
		//if (!skip_LL) {
		MXC_GPIO_OutSet(LL_PORT, LL_PIN);
		tx_buf[0] = 0x3B;
		MXC_Delay(MXC_DELAY_MSEC(1));
		if ((error = MXC_I2C_MasterTransaction(&reqMaster)) != 0) {
			error = (error * -1) + 48;
			tx_data[36] = (char) (error);
			rx_buf[0] = 0;
		}
		ax = rx_buf[0];
		tx_buf[0] = 0x3C;
		MXC_Delay(MXC_DELAY_MSEC(1));
		if ((error = MXC_I2C_MasterTransaction(&reqMaster)) != 0) {
			error = (error * -1) + 48;
			tx_data[36] = (char) (error);
			rx_buf[0] = 0;
		}
		ax = (ax << 8) | rx_buf[0];
		tx_buf[0] = 0x3D;
		MXC_Delay(MXC_DELAY_MSEC(1));
		if ((error = MXC_I2C_MasterTransaction(&reqMaster)) != 0) {
			error = (error * -1) + 48;
			tx_data[36] = (char) (error);
			rx_buf[0] = 0;
		}
		ay = rx_buf[0];
		tx_buf[0] = 0x3E;
		MXC_Delay(MXC_DELAY_MSEC(1));
		if ((error = MXC_I2C_MasterTransaction(&reqMaster)) != 0) {
			error = (error * -1) + 48;
			tx_data[36] = (char) (error);
			rx_buf[0] = 0;
		}
		ay = (ay << 8) | rx_buf[0];
		tx_buf[0] = 0x3F;
		MXC_Delay(MXC_DELAY_MSEC(1));
		if ((error = MXC_I2C_MasterTransaction(&reqMaster)) != 0) {
			error = (error * -1) + 48;
			tx_data[36] = (char) (error);
			rx_buf[0] = 0;
		}
		az = rx_buf[0];
		tx_buf[0] = 0x40;
		MXC_Delay(MXC_DELAY_MSEC(1));
		if ((error = MXC_I2C_MasterTransaction(&reqMaster)) != 0) {
			error = (error * -1) + 48;
			tx_data[36] = (char) (error);
			rx_buf[0] = 0;
		}
		az = (az << 8) | rx_buf[0];
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

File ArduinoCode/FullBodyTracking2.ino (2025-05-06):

#include<Wire.h>
#include <SoftwareSerial.h>
#include <MPU6050.h>

MPU6050 mpu[6];  // Array of 6 MPU6050 objects

SoftwareSerial BTserial(2, 3); // RX | TX

// Digital pins controlling the AD0 pin of each MPU (Pins 2 to 7)
int AD0_pins[] = {4, 5, 6, 7, 8, 9};

const int MPU6050_addr=0x69;

int16_t AccX,AccY,AccZ,Temp,GyroX,GyroY,GyroZ;

void setup() {
  BTserial.begin(57600);
  Serial.begin(115200);
  Wire.begin(0x69);  // Initialize the I2C bus

  // Initialize each MPU6050 sensor with alternate addresses
  for (int i = 0; i < 6; i++) {
    pinMode(AD0_pins[i], OUTPUT);  // Set the AD0 pins as output
    digitalWrite(AD0_pins[i], HIGH); // Set the AD0 pin low initially to use 0x68 address

    mpu[i].initialize();  // Initialize the MPU6050 sensor

    // Check if the sensor is connected
    if (!mpu[i].testConnection()) {
      digitalWrite(AD0_pins[i], LOW);
      BTserial.print("MPU6050 at index ");
      BTserial.print(i);
      BTserial.print(" not connected!");
      BTserial.println();
      Serial.print("MPU6050 at index ");
      Serial.print(i);
      Serial.print(" not connected!");
      Serial.println();
    } else {
      digitalWrite(AD0_pins[i], LOW);
      BTserial.print("MPU6050 at index ");
      BTserial.print(i);
      BTserial.print(" initialized successfully!");
      BTserial.println();
      Serial.print("MPU6050 at index ");
      Serial.print(i);
      Serial.print(" initialized successfully!");
      Serial.println();
    }

    digitalWrite(AD0_pins[i], LOW);
  }
}

void loop(){
  for(int i = 0; i < 6; i++)
  {
    Wire.setWireTimeout(10000, true);
    digitalWrite(AD0_pins[i], HIGH); // Set the AD0 pin low initially to use 0x68 address

    Wire.beginTransmission(MPU6050_addr);
    Wire.write(0x3B);
    Wire.endTransmission(false);

    Wire.requestFrom(MPU6050_addr,14,true);

    AccX=Wire.read()<<8|Wire.read();
    AccY=Wire.read()<<8|Wire.read();
    AccZ=Wire.read()<<8|Wire.read();
    Temp=Wire.read()<<8|Wire.read();
    GyroX=Wire.read()<<8|Wire.read();
    GyroY=Wire.read()<<8|Wire.read();
    GyroZ=Wire.read()<<8|Wire.read();

    Serial.print(i);
    Serial.print(": AX "); Serial.print(AccX);
    Serial.print(" AY "); Serial.print(AccY);
    Serial.print(" AZ "); Serial.print(AccZ);
    Serial.print(" GX "); Serial.print(GyroX);
    Serial.print(" GY "); Serial.print(GyroY);
    Serial.print(" GZ "); Serial.println(GyroZ);

    BTserial.print(i);
    BTserial.print(": AX "); BTserial.print(AccX);
    BTserial.print(" AY "); BTserial.print(AccY);
    BTserial.print(" AZ "); BTserial.print(AccZ);
    BTserial.print(" GX "); BTserial.print(GyroX);
    BTserial.print(" GY "); BTserial.print(GyroY);
    BTserial.print(" GZ "); BTserial.println(GyroZ);

    Wire.endTransmission(true);
    digitalWrite(AD0_pins[i], LOW);
    Wire.clearWireTimeoutFlag();

    delay(10);
  }
}
